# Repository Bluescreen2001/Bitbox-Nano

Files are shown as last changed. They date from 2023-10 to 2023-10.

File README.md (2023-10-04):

# Bitbox-Nano
This is an alternative PCB to makabuf's bitbox game console

## WARNING: this hardware has not been checked for functionality yet!!!

I want to use a special case for the console, so I created this version of the PCB.
I added an ESP32 which is also connected to the VGA signals and the STM32's SDWI interface lines. 
With this additions the ESP can program and debug the STM. It also can generate VGA signals, so hopefully you can also use the ESP VGA libs to generate video. You have to consoles in one device.

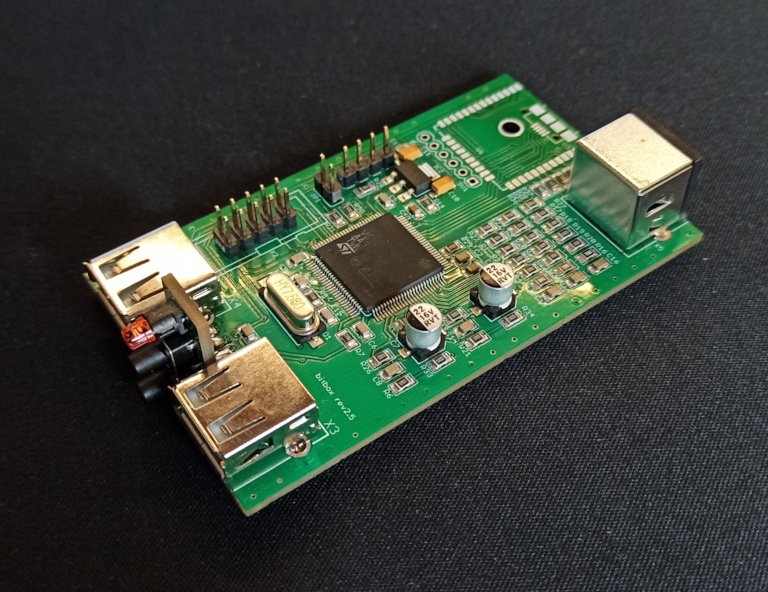
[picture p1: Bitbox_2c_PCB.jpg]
Bitbox 2c PCB


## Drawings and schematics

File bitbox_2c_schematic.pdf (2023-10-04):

GND 1 | GND 15
BitBox | Rev2c

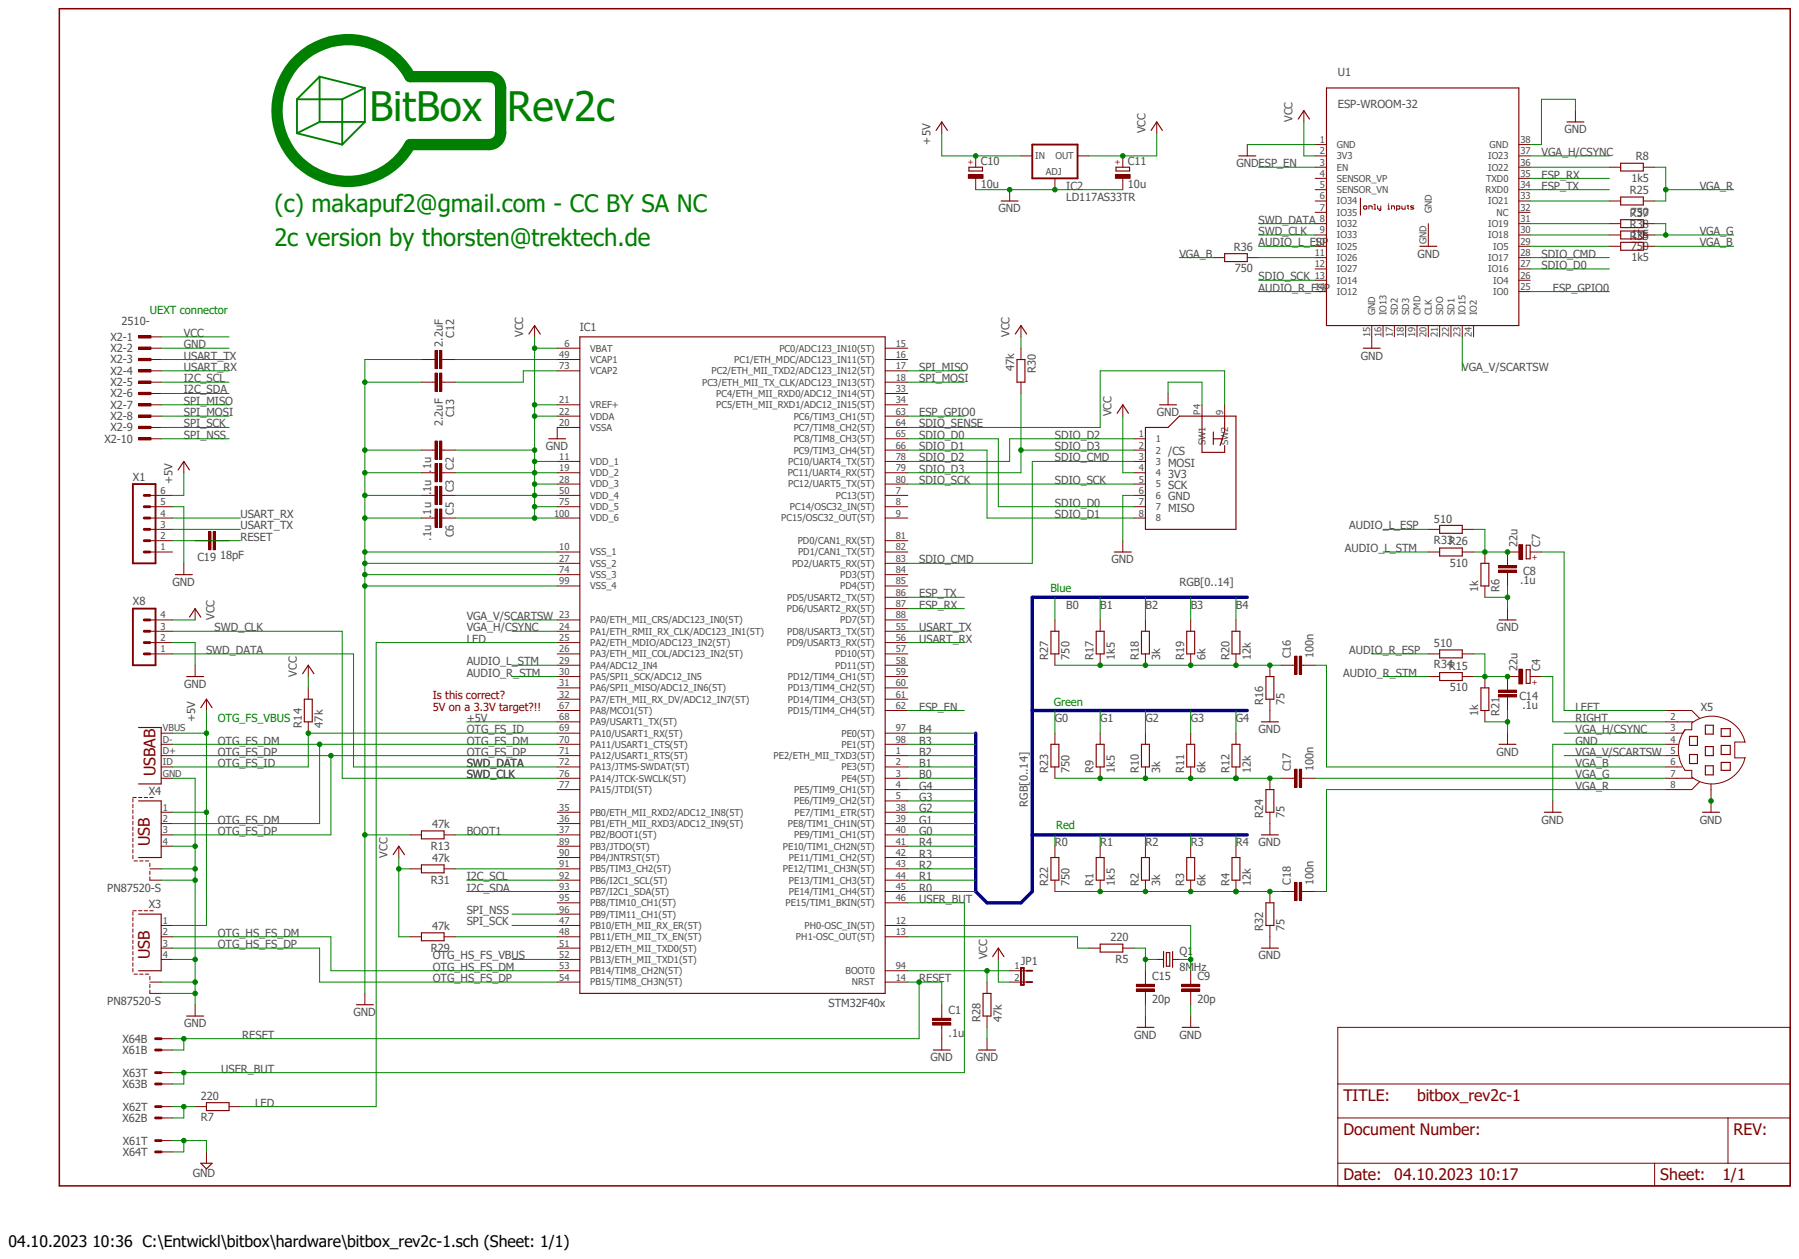
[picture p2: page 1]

(c) makapuf2@gmail.com - CC BY SA NC
2c version by thorsten@trektech.de

VCAP2 73
VREF+ 21 | SPI_MOSI

OTG_FS_DP | | | OTG_FS_DP | PA12/USART1_RTS(5T) 71 PA13/JTMS-SWDAT(5T) 72 | B2

PA11/USART1_CTS(5T) 70 | B3

ID | OTG_FS_ID | | | | SWD_DATA | | B1
GND | OTG_FS_DM | | | | SWD_CLK | PA14/JTCK-SWCLK(5T) 76 | B0

4 | | OTG_HS_FS_DM | PB3/JTDO(5T) 89

PB4/JNTRST(5T) 90 | R3
PB5/TIM3_CH2(5T) 91 | R2

Document Number: | REV:

Date: 04.10.2023 10:17 | Sheet: 1/1

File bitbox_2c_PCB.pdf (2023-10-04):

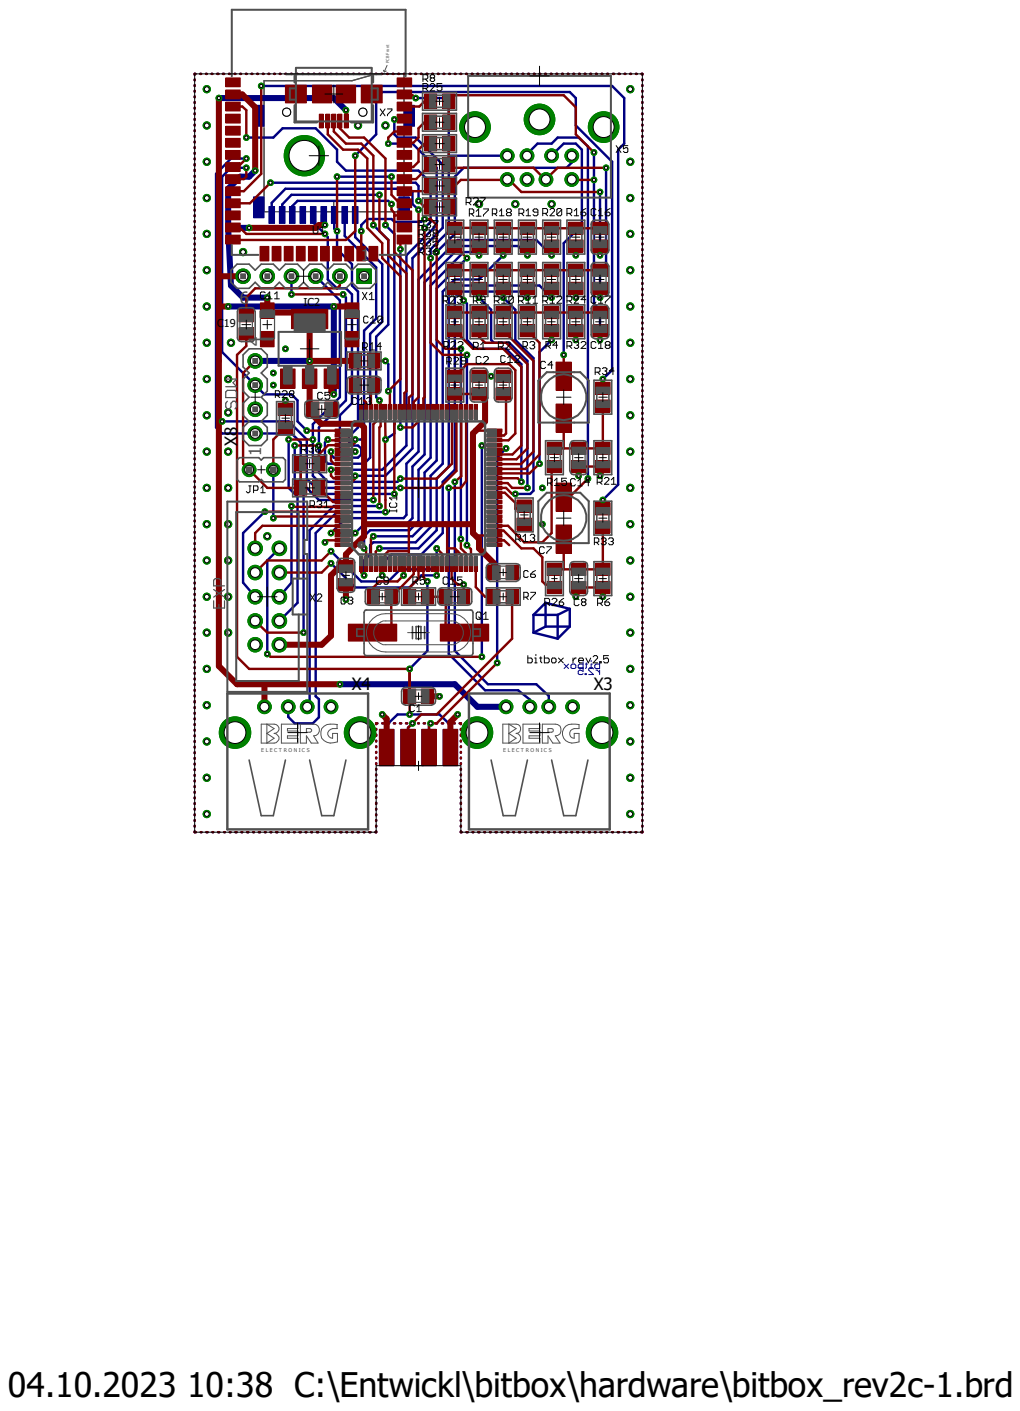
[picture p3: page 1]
PCB Front X4

04.10.2023 10:38 C:\Entwickl\bitbox\hardware\bitbox_rev2c-1.brd

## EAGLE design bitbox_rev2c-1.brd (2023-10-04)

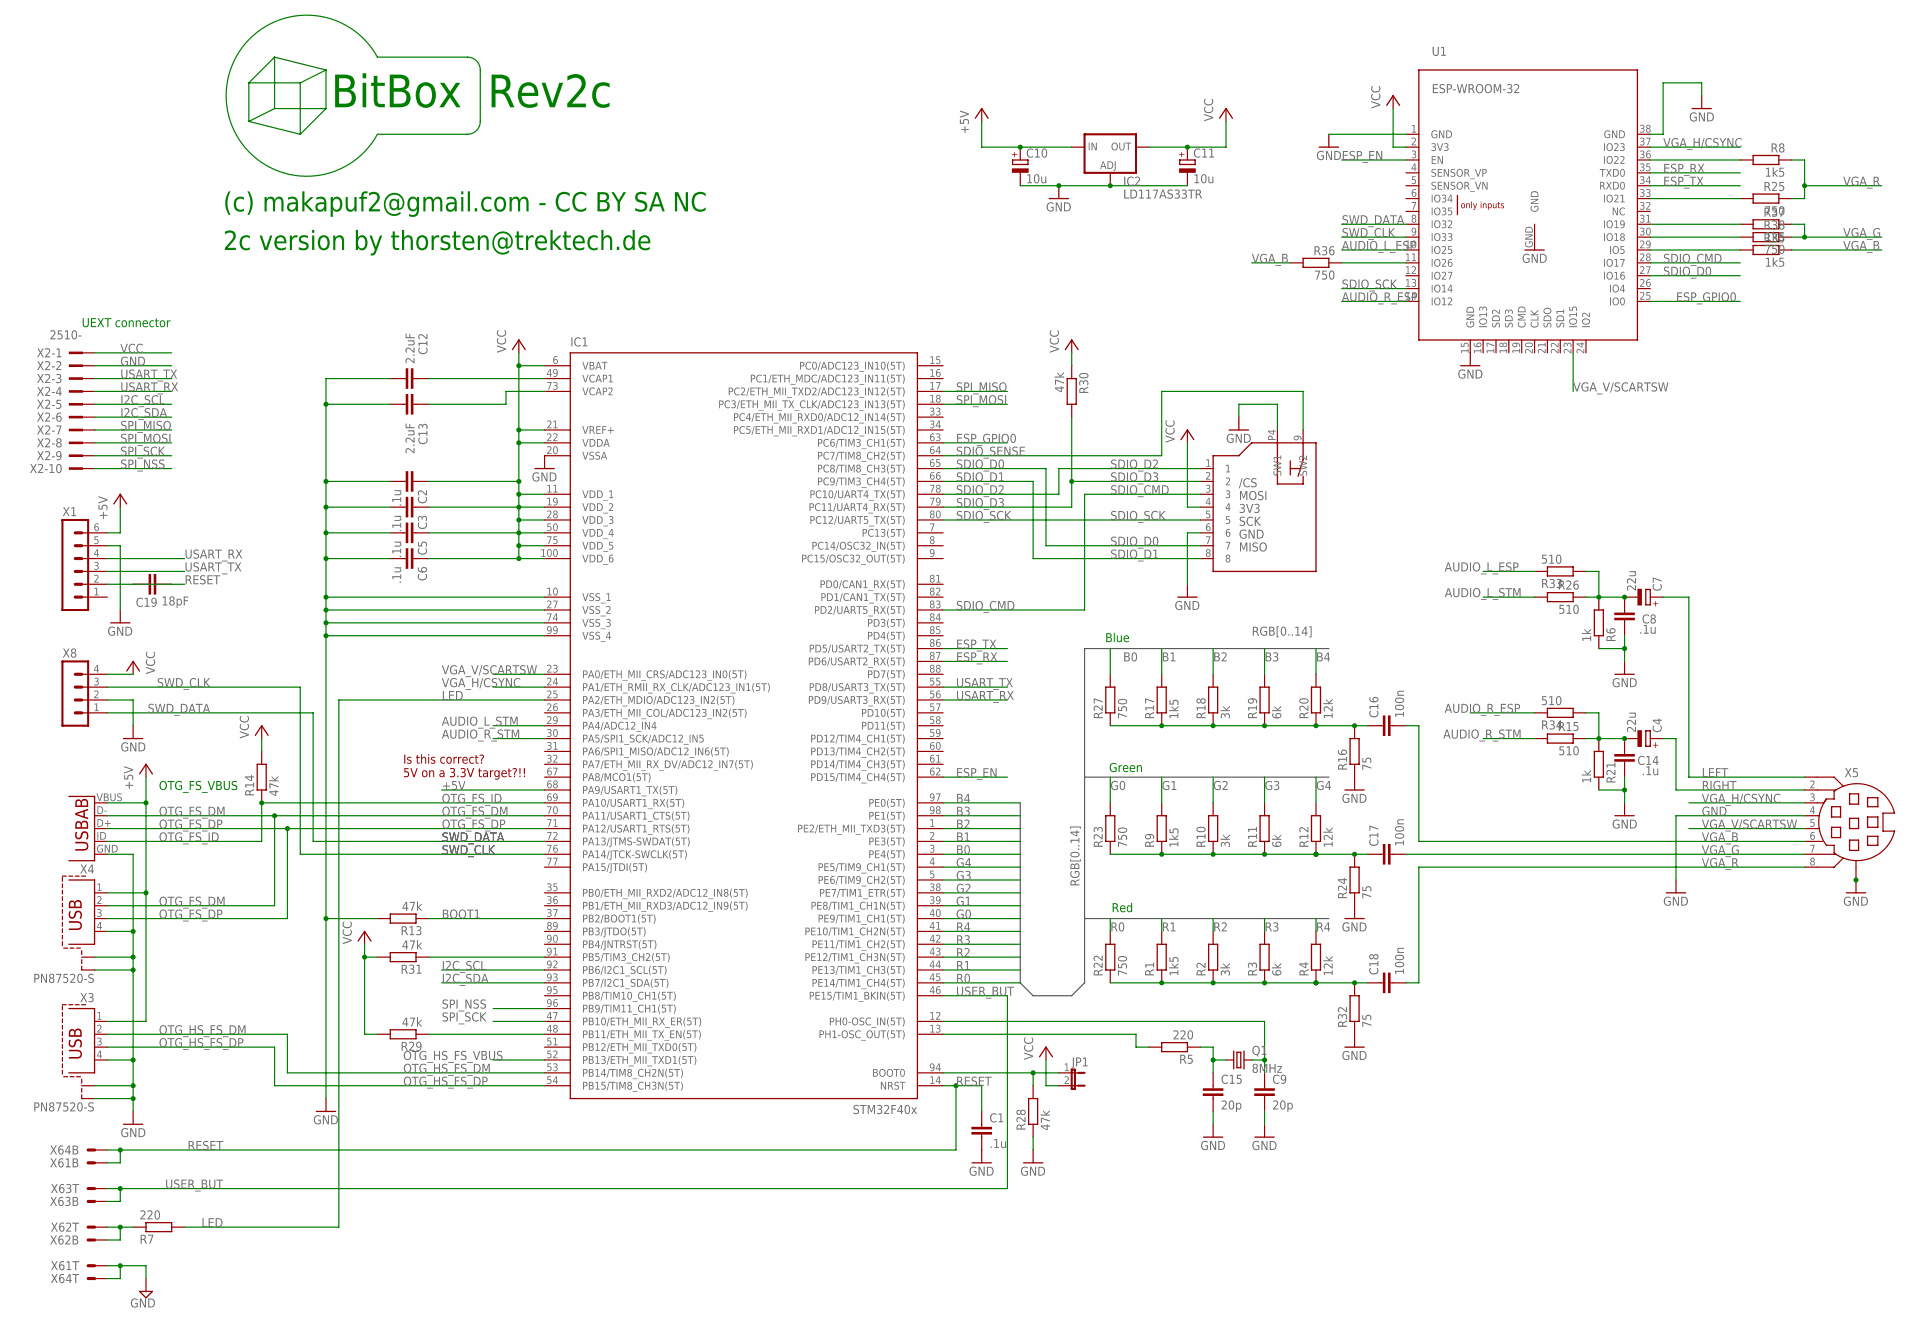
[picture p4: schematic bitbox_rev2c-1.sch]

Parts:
C1, C2, C3, C5, C6, C8, C14: .1u; C0805
C4, C7: 22u; 153CLV-0505
C9, C15: 20p; C0805
C10, C11: 10u; SMC_A
C12, C13: 2.2uF; C0805
C16, C17, C18: 100n; C0805
C19: 18pF; C0805
IC1: STM32F407V; TQFP100
IC2: LD117AS33TR; SOT223
J1: MICROSD-SWITCH; MICROSD-ATOM
JP1: JP1E; JP1
Q1: 8MHz; SM49
R1, R8, R9, R17, R35, R37: 1k5; R0805
R2, R10, R18: 3k; R0805
R3, R11, R19: 6k; R0805
R4, R12, R20: 12k; R0805
R5, R7: 220; R0805
R6, R21: 1k; R0805
R13, R14, R28, R29, R30, R31: 47k; R0805
R15, R26, R33, R34: 510; R0805
R16, R24, R32: 75; R0805
R22, R23, R25, R27, R36, R38: 750; R0805
U1: ESP-WROOM-32
X1: MA06-1
X2: 2510-; PAK100/2500-10
X3, X4: PN87520-S
X5: MINI-DIN-8
X6: PCB_CONNECTOR_4X2; PCB_CONNECTOR_2X4POL
X7: USB-AB; USB-AB-MICRO-SMD
X8: MA04-1

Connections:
+5V: C10.+, IC1.68 (PA9/USART1_TX(5T)), IC2.3 (IN), X1.6, X3.1, X4.1, X7.VBUS
AUDIO_L: C7.-, C8.1, R6.2, R26.1, R33.2
AUDIO_L_ESP: R33.1, U1.10 (IO25)
AUDIO_L_STM: IC1.29 (PA4/ADC12_IN4), R26.2
AUDIO_R: C4.-, C14.1, R15.1, R21.2, R34.2
AUDIO_R_ESP: R34.1, U1.14 (IO12)
AUDIO_R_STM: IC1.30 (PA5/SPI1_SCK/ADC12_IN5), R15.2
B0: IC1.3 (PE4(5T)), R27.2
B1: IC1.2 (PE3(5T)), R17.2
B2: IC1.1 (PE2/ETH_MII_TXD3(5T)), R18.2
B3: IC1.98 (PE1(5T)), R19.2
B4: IC1.97 (PE0(5T)), R20.2
BOOT1: IC1.37 (PB2/BOOT1(5T)), R13.1
ESP_EN: IC1.62 (PD15/TIM4_CH4(5T)), U1.3 (EN)
ESP_GPIO0: IC1.63 (PC6/TIM3_CH1(5T)), U1.25 (IO0)
ESP_RX: IC1.87 (PD6/USART2_RX(5T)), U1.35 (TXD0)
ESP_TX: IC1.86 (PD5/USART2_TX(5T)), U1.34 (RXD0)
G0: IC1.40 (PE9/TIM1_CH1(5T)), R23.2
G1: IC1.39 (PE8/TIM1_CH1N(5T)), R9.2
G2: IC1.38 (PE7/TIM1_ETR(5T)), R10.2
G3: IC1.5 (PE6/TIM9_CH2(5T)), R11.2
G4: IC1.4 (PE5/TIM9_CH1(5T)), R12.2
GND: C1.2, C2.2, C3.2, C5.2, C6.2, C8.2, C9.2, C10.-, C11.-, C12.2, C13.2, C14.2, C15.2, IC1.10 (VSS_1), IC1.20 (VSSA), IC1.27 (VSS_2), IC1.74 (VSS_3), IC1.99 (VSS_4), IC2.1 (ADJ), J1.6, J1.P4 (SW1), R6.1, R13.2, R16.1, R21.1, R24.1, R28.1, R32.1, U1.1 (GND), U1.15 (GND), U1.38 (GND), U1.GND, X1.5, X2.2, X3.4, X3.S1, X3.S2, X4.4, X4.S1, X4.S2, X5.4, X5.G (G1), X6.1T, X6.4T, X7.GND, X8.2
I2C_SCL: IC1.92 (PB6/I2C1_SCL(5T)), X2.5
I2C_SDA: IC1.93 (PB7/I2C1_SDA(5T)), X2.6
LED: IC1.25 (PA2/ETH_MDIO/ADC123_IN2(5T)), R7.2
LEFT: C7.+, X5.1
unnamed: C19.2, X1.2
unnamed: C13.1, IC1.73 (VCAP2)
unnamed: C16.1, R16.2, R17.1, R18.1, R19.1, R20.1, R27.1
unnamed: C12.1, IC1.49 (VCAP1)
unnamed: R8.2, U1.36 (IO22)
unnamed: C15.1, Q1.1, R5.1
unnamed: C9.1, IC1.12 (PH0-OSC_IN(5T)), Q1.2
unnamed: C17.1, R9.1, R10.1, R11.1, R12.1, R23.1, R24.2
unnamed: R25.2, U1.33 (IO21)
unnamed: IC1.91 (PB5/TIM3_CH2(5T)), R31.1
unnamed: R37.2, U1.31 (IO19)
unnamed: IC1.13 (PH1-OSC_OUT(5T)), R5.2
unnamed: IC1.94 (BOOT0), JP1.1, R28.2
unnamed: R38.2, U1.30 (IO18)
unnamed: R35.2, U1.29 (IO5)
unnamed: R7.1, X6.2B, X6.2T
unnamed: C18.1, R1.1, R2.1, R3.1, R4.1, R22.1, R32.2
unnamed: R36.1, U1.11 (IO26)
OTG_FS_DM: IC1.70 (PA11/USART1_CTS(5T)), X4.2, X7.D-
OTG_FS_DP: IC1.71 (PA12/USART1_RTS(5T)), X4.3, X7.D+
OTG_FS_ID: IC1.69 (PA10/USART1_RX(5T)), R14.1, X7.ID (USBID)
OTG_HS_FS_DM: IC1.53 (PB14/TIM8_CH2N(5T)), X3.2
OTG_HS_FS_DP: IC1.54 (PB15/TIM8_CH3N(5T)), X3.3
OTG_HS_FS_VBUS: IC1.52 (PB13/ETH_MII_TXD1(5T))
R0: IC1.45 (PE14/TIM1_CH4(5T)), R22.2
R1: IC1.44 (PE13/TIM1_CH3(5T)), R1.2
R2: IC1.43 (PE12/TIM1_CH3N(5T)), R2.2
R3: IC1.42 (PE11/TIM1_CH2(5T)), R3.2
R4: IC1.41 (PE10/TIM1_CH2N(5T)), R4.2
RESET: C1.1, C19.1, IC1.14 (NRST), X6.1B, X6.4B
RIGHT: C4.+, X5.2
SDIO_CMD: IC1.83 (PD2/UART5_RX(5T)), J1.3, U1.28 (IO17)
SDIO_D0: IC1.65 (PC8/TIM8_CH3(5T)), J1.7, U1.27 (IO16)
SDIO_D1: IC1.66 (PC9/TIM3_CH4(5T)), J1.8
SDIO_D2: IC1.78 (PC10/UART4_TX(5T)), J1.1
SDIO_D3: IC1.79 (PC11/UART4_RX(5T)), J1.2, R30.2
SDIO_SCK: IC1.80 (PC12/UART5_TX(5T)), J1.5, U1.13 (IO14)
SDIO_SENSE: IC1.64 (PC7/TIM8_CH2(5T)), J1.9 (SW2)
SPI_MISO: IC1.17 (PC2/ETH_MII_TXD2/ADC123_IN12(5T)), X2.7
SPI_MOSI: IC1.18 (PC3/ETH_MII_TX_CLK/ADC123_IN13(5T)), X2.8
SPI_NSS: IC1.96 (PB9/TIM11_CH1(5T)), X2.10
SPI_SCK: IC1.47 (PB10/ETH_MII_RX_ER(5T)), X2.9
SWD_CLK: IC1.76 (PA14/JTCK-SWCLK(5T)), U1.9 (IO33), X8.3
SWD_DATA: IC1.72 (PA13/JTMS-SWDAT(5T)), U1.8 (IO32), X8.1
USART_RX: IC1.56 (PD9/USART3_RX(5T)), X1.4, X2.4
USART_TX: IC1.55 (PD8/USART3_TX(5T)), X1.3, X2.3
USER_BUT: IC1.46 (PE15/TIM1_BKIN(5T)), X6.3B, X6.3T
VCC: C2.1, C3.1, C5.1, C6.1, C11.+, IC1.6 (VBAT), IC1.11 (VDD_1), IC1.19 (VDD_2), IC1.21 (VREF+), IC1.22 (VDDA), IC1.28 (VDD_3), IC1.50 (VDD_4), IC1.75 (VDD_5), IC1.100 (VDD_6), IC2.2 (OUT), IC2.4 (OUT), J1.4, JP1.2, R14.2, R29.2, R30.1, R31.2, U1.2 (3V3), X2.1, X8.4
VGA_B: C16.2, R35.1, R36.2, X5.6
VGA_G: C17.2, R37.1, R38.1, X5.7
VGA_H/CSYNC: IC1.24 (PA1/ETH_RMII_RX_CLK/ADC123_IN1(5T)), U1.37 (IO23), X5.3
VGA_R: C18.2, R8.1, R25.1, X5.8
VGA_V/SCARTSW: IC1.23 (PA0/ETH_MII_CRS/ADC123_IN0(5T)), U1.23 (IO15), X5.5
YYY: IC1.48 (PB11/ETH_MII_TX_EN(5T)), R29.1

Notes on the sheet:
Red
Green
Blue
UEXT connector
OTG_FS_VBUS
BitBox Rev2c
(c) makapuf2@gmail.com - CC BY SA NC
2c version by thorsten@trektech.de
Is this correct? 5V on a 3.3V target?!!

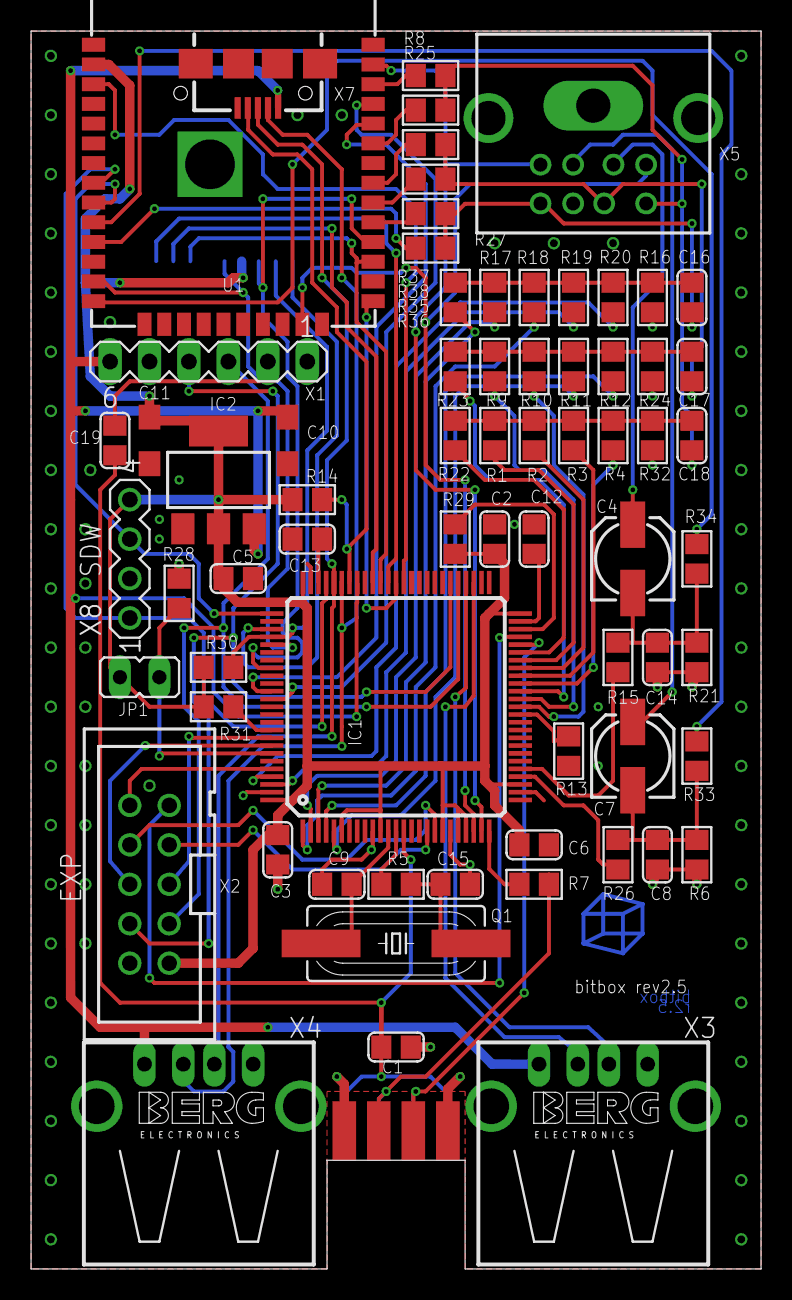
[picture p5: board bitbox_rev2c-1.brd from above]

Board: 2 copper layers, 47.0 x 79.7 mm, 71 parts (1 on the bottom side), 80 nets.

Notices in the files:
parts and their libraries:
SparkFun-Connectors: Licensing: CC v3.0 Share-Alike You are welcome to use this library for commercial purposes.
